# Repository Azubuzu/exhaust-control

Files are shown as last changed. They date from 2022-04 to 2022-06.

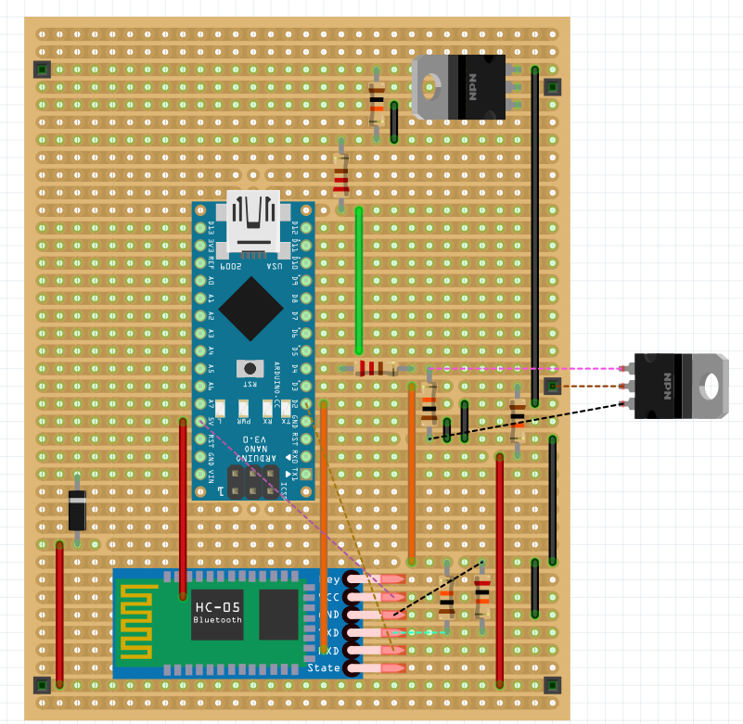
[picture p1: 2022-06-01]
Hardware/veroboard.png

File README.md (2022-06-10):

# exhaust-control
## Bluetooth command

List of available command for exhaust-control bluetooth module

| Command | Response | Description |
| --- | --- | --- |
| valve_open | valve_open OK | Fully open the valve |
| valve_close | valve_close OK | Fully close the valve |
| valve_open_ms XXX | valve_open_ms XXX OK | Open the valve for XXX ms (no limit) |

## Connection between HC-05 and arduino nano

| HC-05 pin | Arduino nano pin |
| --- | --- |
| STATE | Not connected |
| RXD | D2 |
| TXD | D3 |
| GND | GND |
| VCC | 3V3 |
| EN | Not connected |

## Connection between arduino and the mosfets

| Arduino nano pin | Mosfet |
| --- | --- |
| D4 | Control |
| D5 | Power supply |

- Connected on pin 1 (gate) of the mosfets

## Configure the HC-05

- HC-05 on AT mode (press STATE button on power up)
- HC-05 baud rate = 38400
- COM console must have NL&CR

### Change name
```sh
AT+NAME=REMUS
```

### Change password
```sh
AT+PSWD="2802"
```

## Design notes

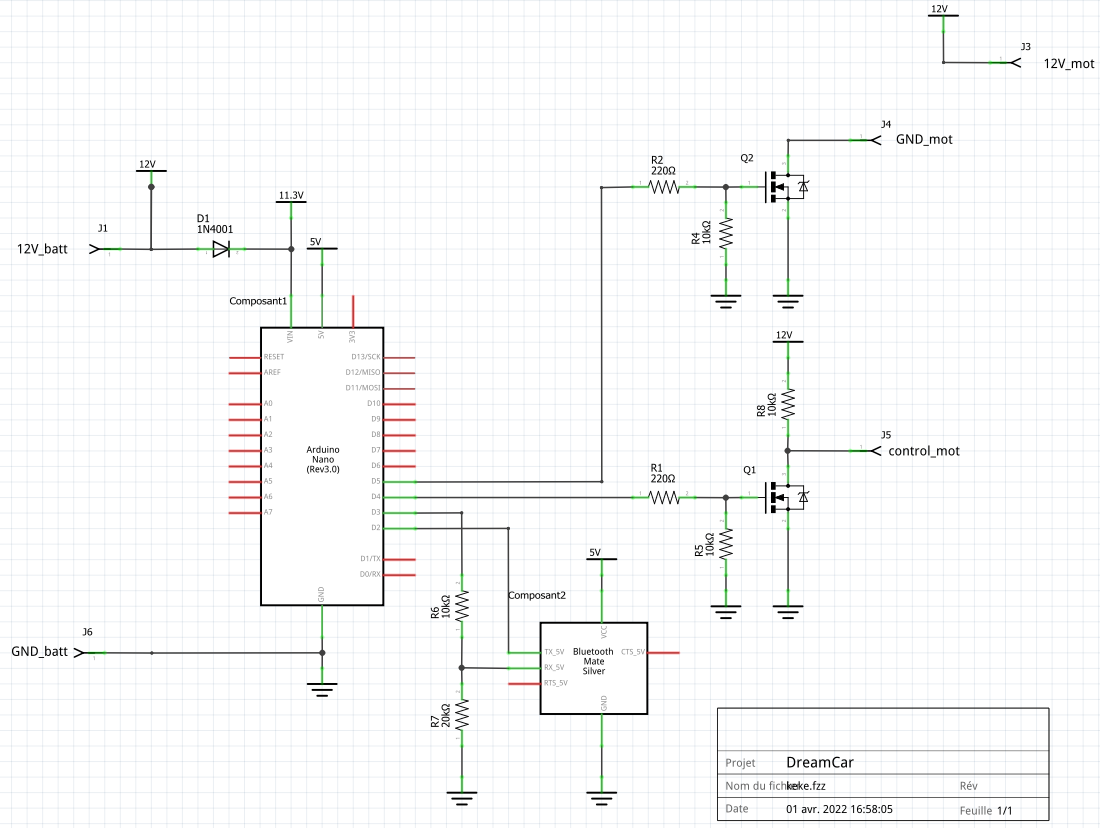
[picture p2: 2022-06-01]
Hardware/schematic.png

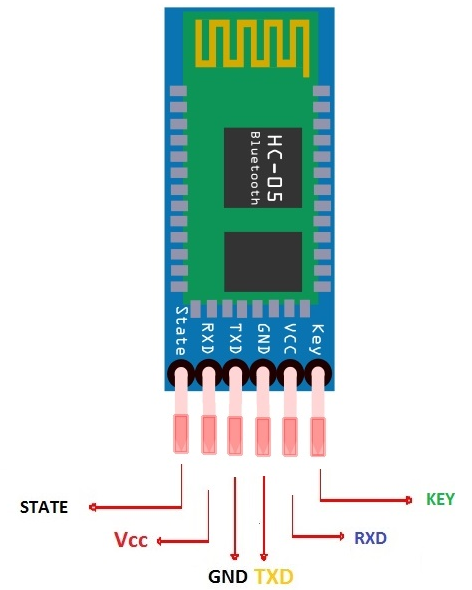
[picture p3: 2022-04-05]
Hardware/Datasheet/hc-05_pinout.png

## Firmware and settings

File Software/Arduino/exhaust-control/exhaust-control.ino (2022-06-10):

#include <SoftwareSerial.h>
// Configurations ///////////////////////////////////////////////////////////////
#define BT_RX 2
#define BT_TX 3
#define MOSFET_CONTROL 4 //Logic is inverted for this mosfet
#define MOSFET_POWER 5
#define FULL_CYCLE_MS 1000
/////////////////////////////////////////////////////////////////////////////////
SoftwareSerial BTserial(BT_TX, BT_RX); // (Nano RX , Nano TX)
/**
 * Init setup
 */
void setup() {
    // Setting up COM terminal for debugging
    Serial.begin(9600);
    Serial.println("Arduino is ready");
 
    // HC-05 default serial speed for communication mode is 9600
    BTserial.begin(9600);  
    Serial.println("BTserial started at 9600");

    // Setting up the nano pin to output for the mosfet control
    pinMode(MOSFET_POWER, OUTPUT);
    pinMode(MOSFET_CONTROL, OUTPUT);
}

/**
 * Main loop
 */
void loop() {
   // Keep reading from HC-05 and send to Arduino Serial Monitor
    if (BTserial.available()) {  
        String code = btReadStringAndClean();
        log(code + " reveived");

        if (code.equals("valve_open")) {
          BTserial.println("valve_open received");
          openValveThenIdle();
          BTserial.println("valve_open OK");
          log("Valve opened");
        }

        if (code.equals("valve_close")) {
          BTserial.println("valve_close received");
          closeValveThenIdle();
          BTserial.println("valve_close OK");
          log("Valve closed");
        }

        if (code.startsWith("valve_open_ms")) {
          BTserial.println("valve_open_ms " + code.substring(14) + " received");
          openValveFor(code.substring(14));
          BTserial.println("valve_open_ms " + code.substring(14) + " OK");
          log("Valve opened for " + code.substring(14) + " ms");
        }
    } 
}

/**
 * Open the valve and let it that way
 */
void openValve() {
    digitalWrite(MOSFET_CONTROL, HIGH);
    digitalWrite(MOSFET_POWER, HIGH);
}

/**
 * Close the valve and let it that way
 */
void closeValve() {
    digitalWrite(MOSFET_CONTROL, LOW);
    digitalWrite(MOSFET_POWER, HIGH);
}

/**
 * Cut the valve alimentation in order to stop the valve were it is
 */
void stopValve() {
    digitalWrite(MOSFET_POWER, LOW);
    digitalWrite(MOSFET_CONTROL, LOW);
}

/**
 * Open the valve for the given time in ms
 */
void openValveFor(String ms) {

    int openFor = ms.toInt();

    if (openFor == 0) {
        return;
    }
    
    closeValve();
    delay(FULL_CYCLE_MS);
    openValve();
    delay(openFor);
    stopValve();
}

/**
* Open the valve then cut the alimentation in order to save power
*/
void openValveThenIdle() {
    openValve();
    delay(FULL_CYCLE_MS);
    stopValve();
}

/**
* Close the valve then cut the alimentation in order to save power
*/
void closeValveThenIdle() {
    closeValve();
    delay(FULL_CYCLE_MS);
    stopValve();
}

/**
* Read string from bluetooth, stop reading when '\n' is detected
* Return trimmed received string
*/
String btReadStringAndClean() {
    String s = BTserial.readStringUntil('\n');
    s.trim();
    return s;
}

/**
* Log a message to the serial port of the arduino
*/
void log(String msg) {
    Serial.println(msg);
}

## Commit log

2022-03-07 Adds example code for arduino nano and hc 05
2022-03-08 Adds missing bt command and moved read string in a method
    [exhaust-control.ino]
2022-03-09 Adds open, close and stop valve functions
2022-03-09 Adds open valve for function
2022-03-09 Closes valve completly before re-open it for a given time
2022-03-15 Updates doc with mosfet pining and HC-05 configuration
2022-04-05 Add hc-05 datasheet and actual Fritzing schematic
    [keke.fzz]
2022-04-05 add resistors
    [keke.fzz]
2022-04-05 add 5V -> 3.3V resistive bridge
    [keke.fzz]
2022-06-01 schematic modified (not on RX/TX arduino but D2 / D3 + veroboard
    [keke.fzz]
2022-06-10 Invert CONTROL MOSFET command caused by design change
    [exhaust-control.ino]
2022-06-10 Open and close valve end in an idle state
2022-06-10 Set the state of the control mosfet before the power one
